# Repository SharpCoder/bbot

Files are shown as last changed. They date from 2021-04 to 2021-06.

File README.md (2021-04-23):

# bbot

bbot - or balancing robot - is a two-wheeled, 3D printed robot which is capable of balancing just like a seguway. The general concept behind the algorithm is: if you are falling forward, move forward. If you are falling backward, move backward. The real challenge comes in doing this quickly and accurately enough.

picture of the robot with most parts assembled

## Components

The main components for bbot are as follows:

 - Adafruit Metro Mini (Arduino)
 - ADXL335 (Accelerometer)
 - SparkFun OpenLog (Telemetry to SDCard)
 - 595N (Shift Register)
 - 2x L293D (H-Bridge)
 - 2x Stepper Motors

## Project Files

The project is split out into different folders. Each folder is responsible for a different aspect of the robot design.

 - **bbot-firmware**: _The arduino source code_
 - **bbot-jupyter**: _A jupyter notebook used to analyze sensor readings_
 - **bbot-models**: _SolidWorks models, as well as finalized STL files_
 - **bbot-pcb**: _KiCAD circuit board and gerber files_

## bbot-firmware

### Overview

The algorithm which is currently implemented takes the approach of measuring the accelerometer sensor readings every 30ms and then comparing the observed values with a known threshold. If the readings indicate it is tilting forward, the robot will activate the step-forward routine for each motor. If the readings indicate it is tilting backward, the robot will activate the step-backward routine for each motor.

In order to actually move the motors, two primary files are responsible. The first being `motors.h` and `motors.cpp`. This code is designed to track which phase of each motor is active at any point in time. Knowing what phase is active allows us to determine what move to take in order to transition to a forward or backward step state. The H-Bridge is actually wired up to a shift register and to activate it, we must keep track of which pins are active in the shift register. The code which handles this is in the files `shift.h` and `shift.cpp`. Managing the shift register is relatively straightforward and simply requires sending an int array containing the state of each pin.

Collecting telemetry is an important part of this project, so that the thresholds can be tweaked in order to improve the algorithm. The `logger.h` and `logger.cpp` files are responsible for this. By leveraging a Sparkfun OpenLog, we are able to stream telemetry data to an SDCard. Each time the sensor is observed, its readings are written to the SDCard.

### Building

You can build the code through the arduino IDE. The microcontroller I used is the Adafruit Metro Mini, which is compatible with most Arduino board targets (for example: Arduino Pro Mini).

## Jupyter Notebook

## 3D Models
TBD

## Assembly Instructions
TBD

## License

All source code and models are provided under the MIT license.

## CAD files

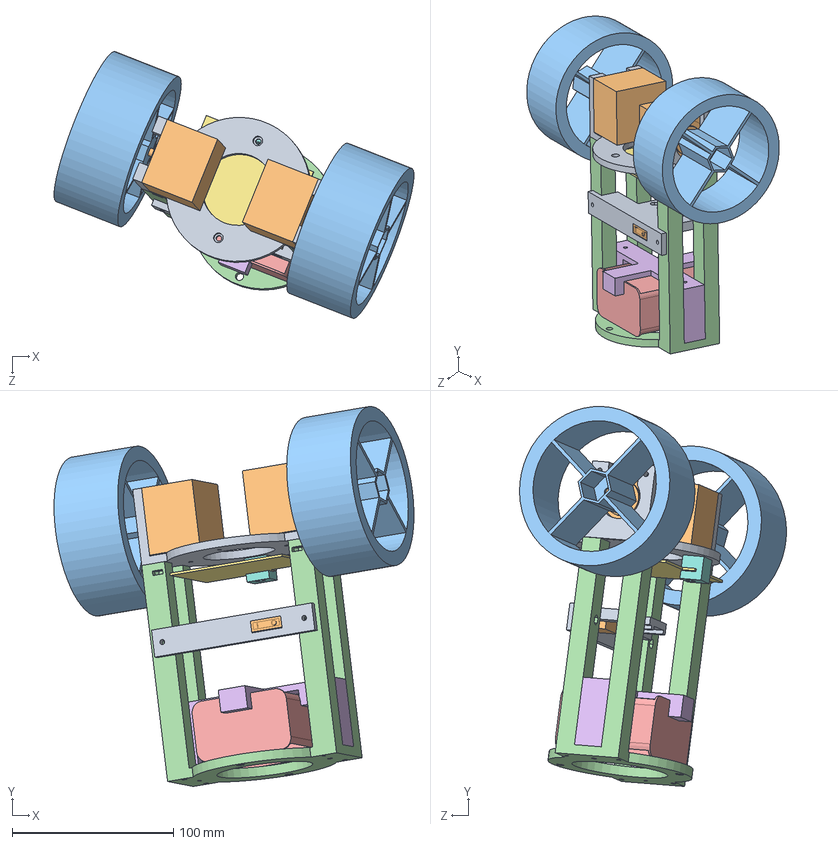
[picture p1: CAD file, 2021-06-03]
bbot-models/full-assembly.SLDASM
223.2 x 235.6 x 165.5 mm
motor-mount
nema17 x 2
wheel x 2
deck
battery-pack
battery-mount
circuit-board
circuit-board-mount
mid-deck
switch

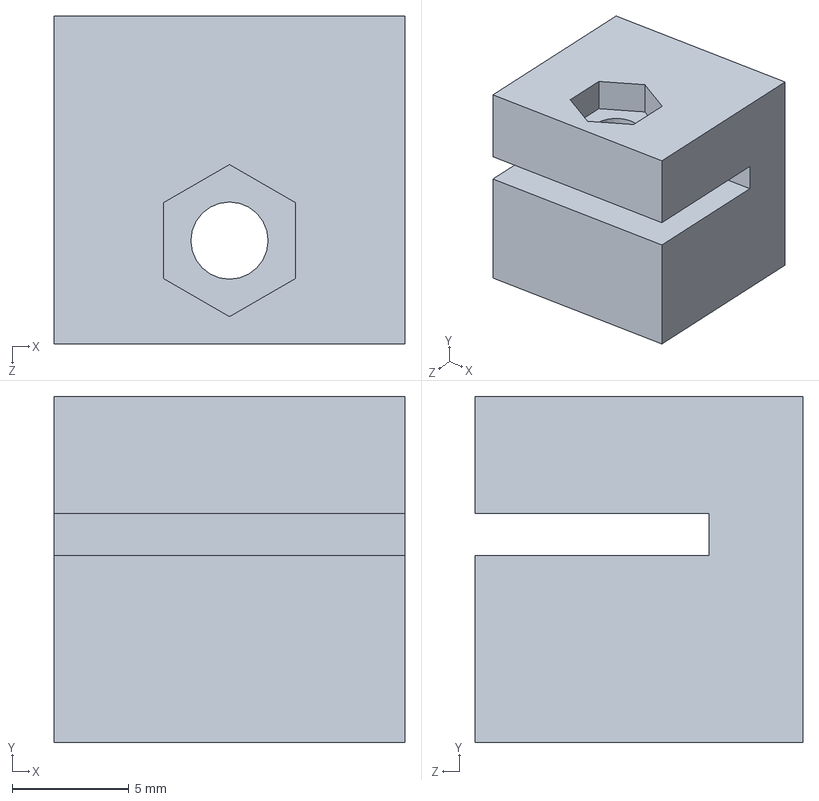
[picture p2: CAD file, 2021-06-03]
bbot-models/chassis/circuit-board-mount.SLDPRT
15.0 x 14.8 x 14.0 mm

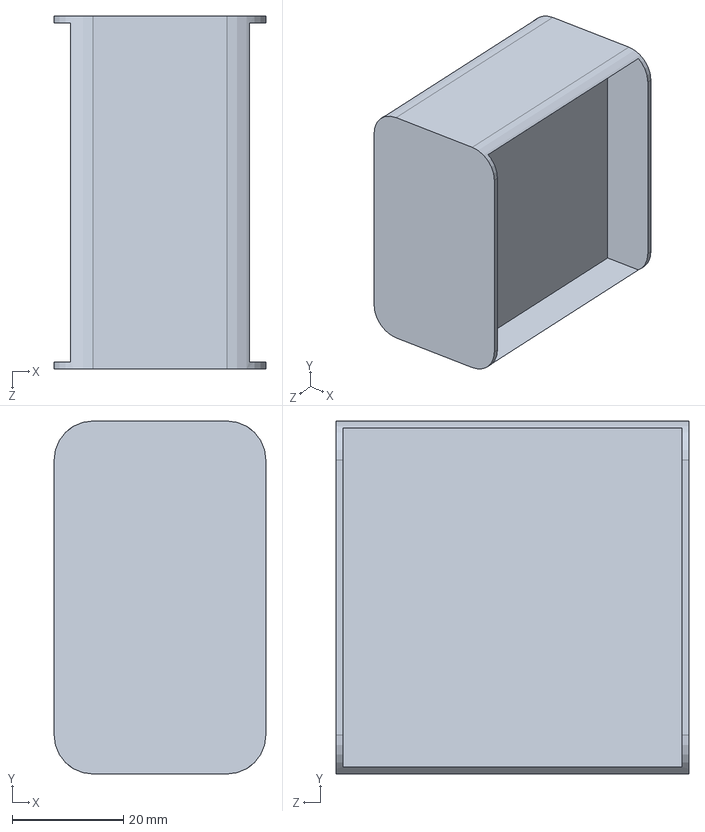
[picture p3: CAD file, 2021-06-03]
bbot-models/cosmetic/battery-pack.SLDPRT
38.1 x 63.5 x 63.5 mm

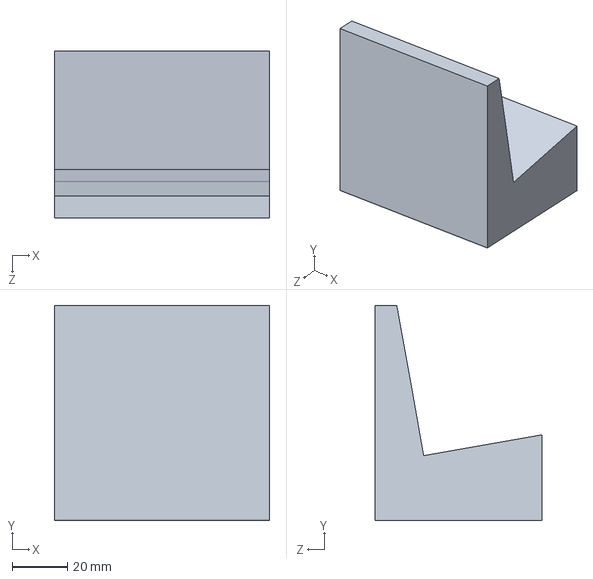
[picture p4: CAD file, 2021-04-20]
bbot-models/debug/block-10d-angle.SLDPRT
78.0 x 78.0 x 60.8 mm

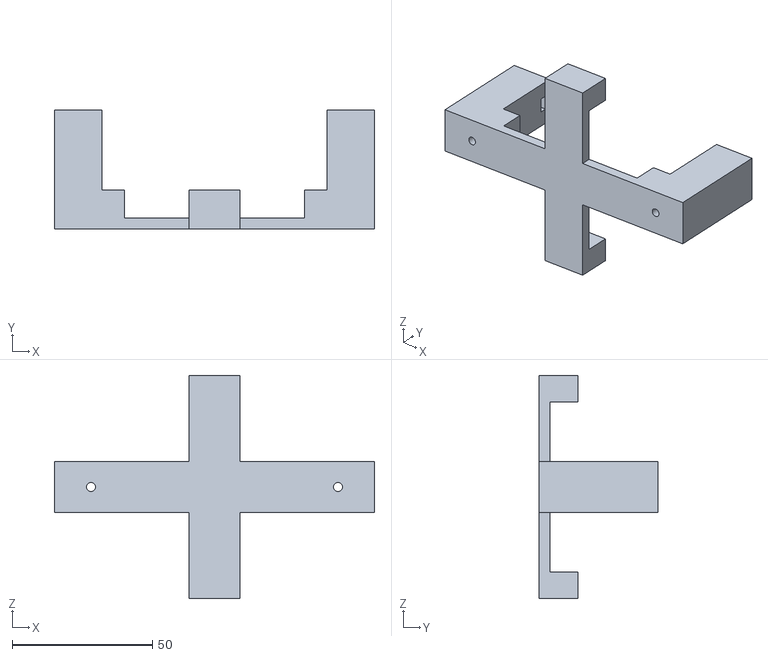
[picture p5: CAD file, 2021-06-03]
bbot-models/STL_FILES/battery-mount.STL
114.0 x 42.5 x 79.5

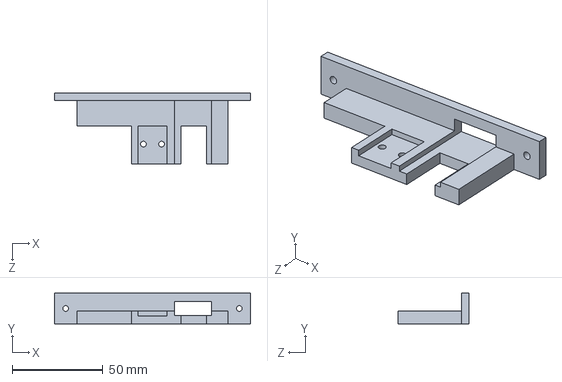
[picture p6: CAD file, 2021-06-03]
bbot-models/chassis/mid-deck.SLDPRT
108.0 x 17.0 x 39.2 mm

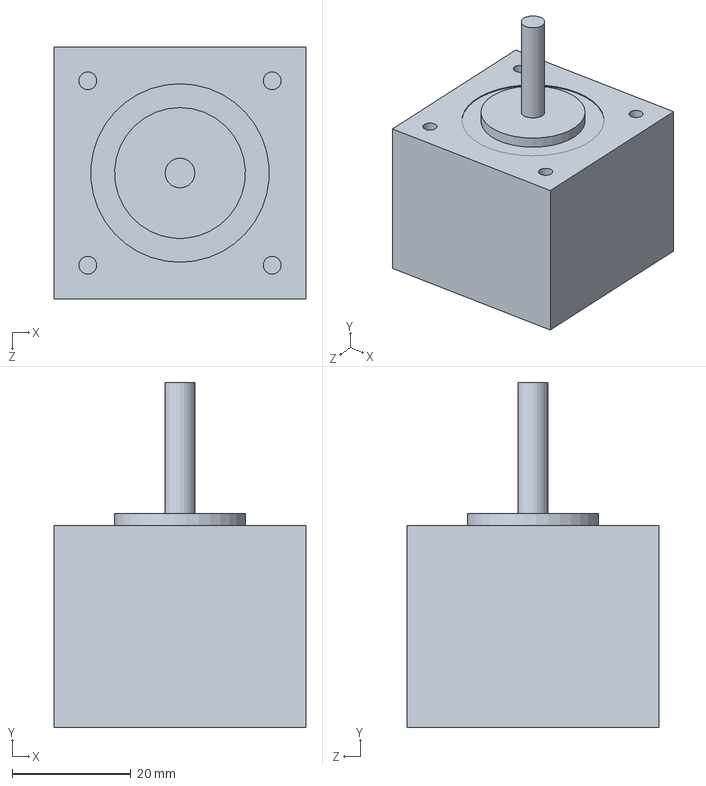
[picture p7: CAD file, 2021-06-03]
bbot-models/cosmetic/nema17.SLDPRT
42.3 x 58.0 x 42.3 mm

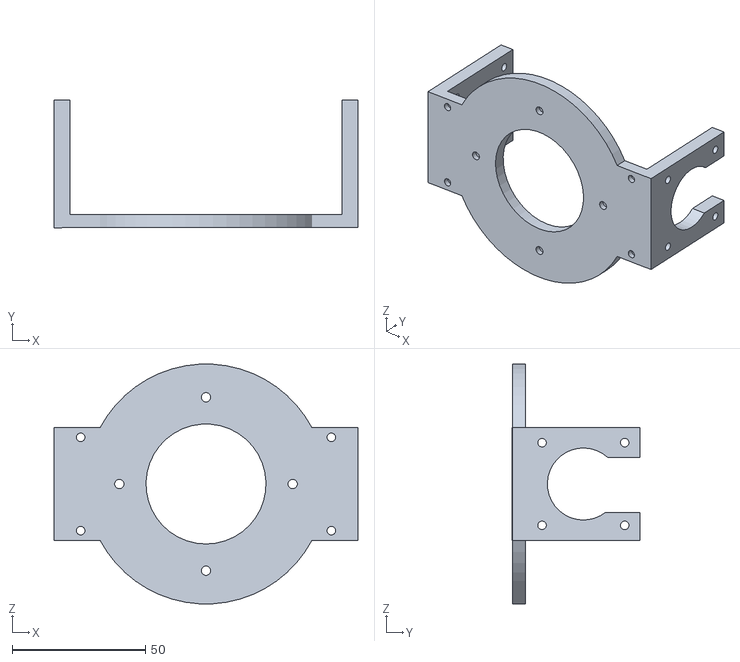
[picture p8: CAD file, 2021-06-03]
bbot-models/STL_FILES/motor-mount.STL
114.0 x 47.8 x 89.9

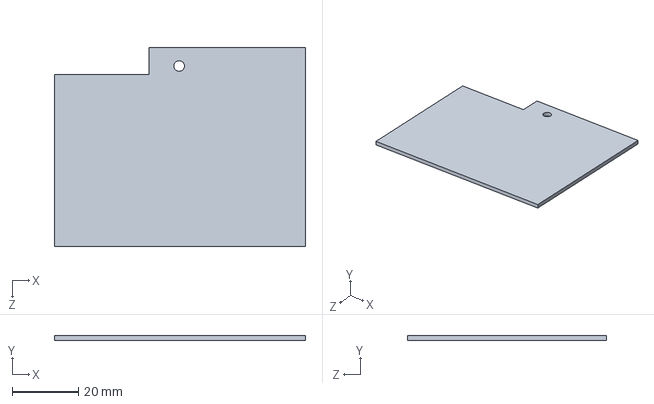
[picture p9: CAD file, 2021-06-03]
bbot-models/cosmetic/circuit-board.SLDPRT
75.7 x 1.50 x 60.0 mm

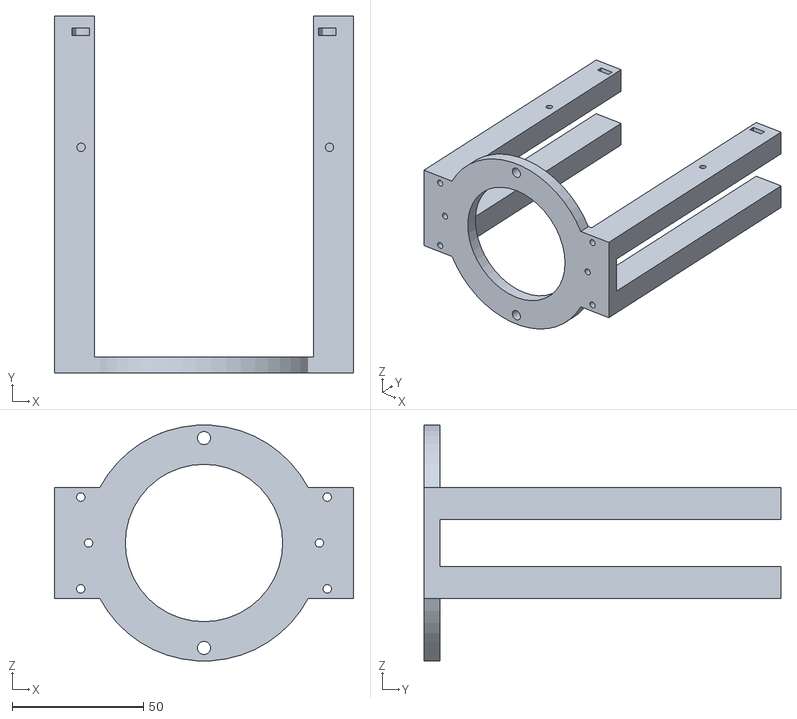
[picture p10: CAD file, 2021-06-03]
bbot-models/STL_FILES/deck.STL
114.0 x 136.0 x 89.8

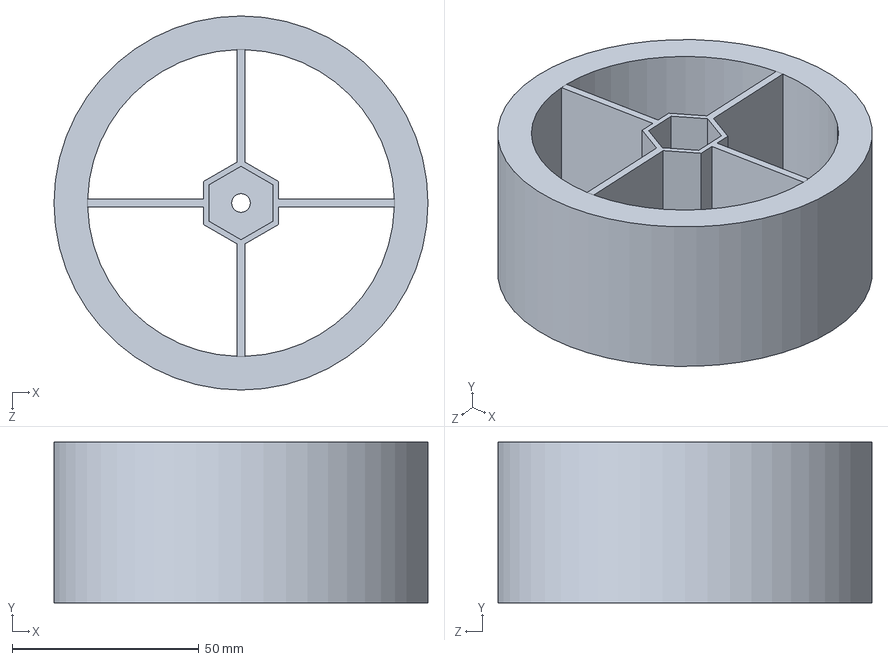
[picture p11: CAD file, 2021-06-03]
bbot-models/cosmetic/wheel.SLDPRT
100.0 x 43.0 x 100.0 mm

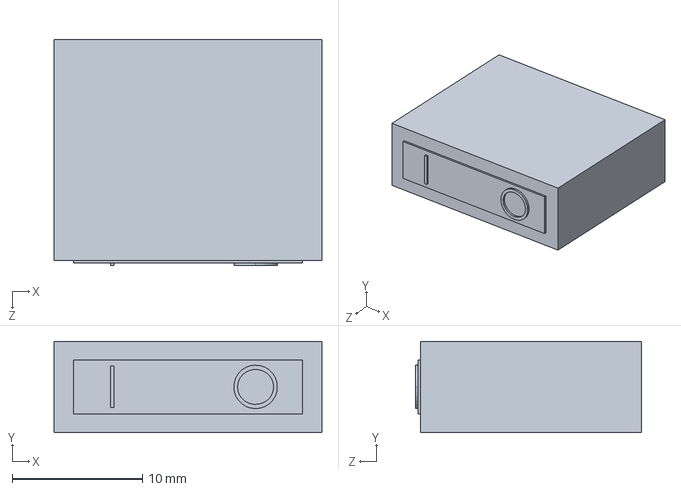
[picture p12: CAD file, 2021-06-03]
bbot-models/cosmetic/switch.SLDPRT
20.6 x 7.00 x 17.4 mm

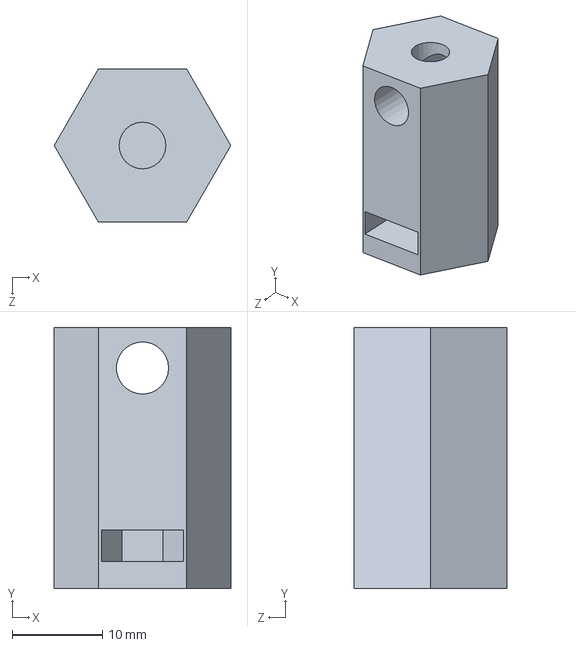
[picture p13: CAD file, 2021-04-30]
bbot-models/chassis/wheel-mount.SLDPRT
19.6 x 29.0 x 17.0 mm

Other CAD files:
bbot-models/chassis/motor-mount.SLDPRT
bbot-models/chassis/battery-mount.SLDPRT
bbot-models/STL_FILES/circuit-board-mount.STL
bbot-models/chassis/deck.SLDPRT
bbot-models/STL_FILES/mid-deck.STL
bbot-models/STL_FILES/block-10d-angle.STL
bbot-models/STL_FILES/washer.STL
bbot-models/STL_FILES/wheel-mount.STL
bbot-models/chassis/washer.SLDPRT
bbot-models/cosmetic/component-box.SLDPRT

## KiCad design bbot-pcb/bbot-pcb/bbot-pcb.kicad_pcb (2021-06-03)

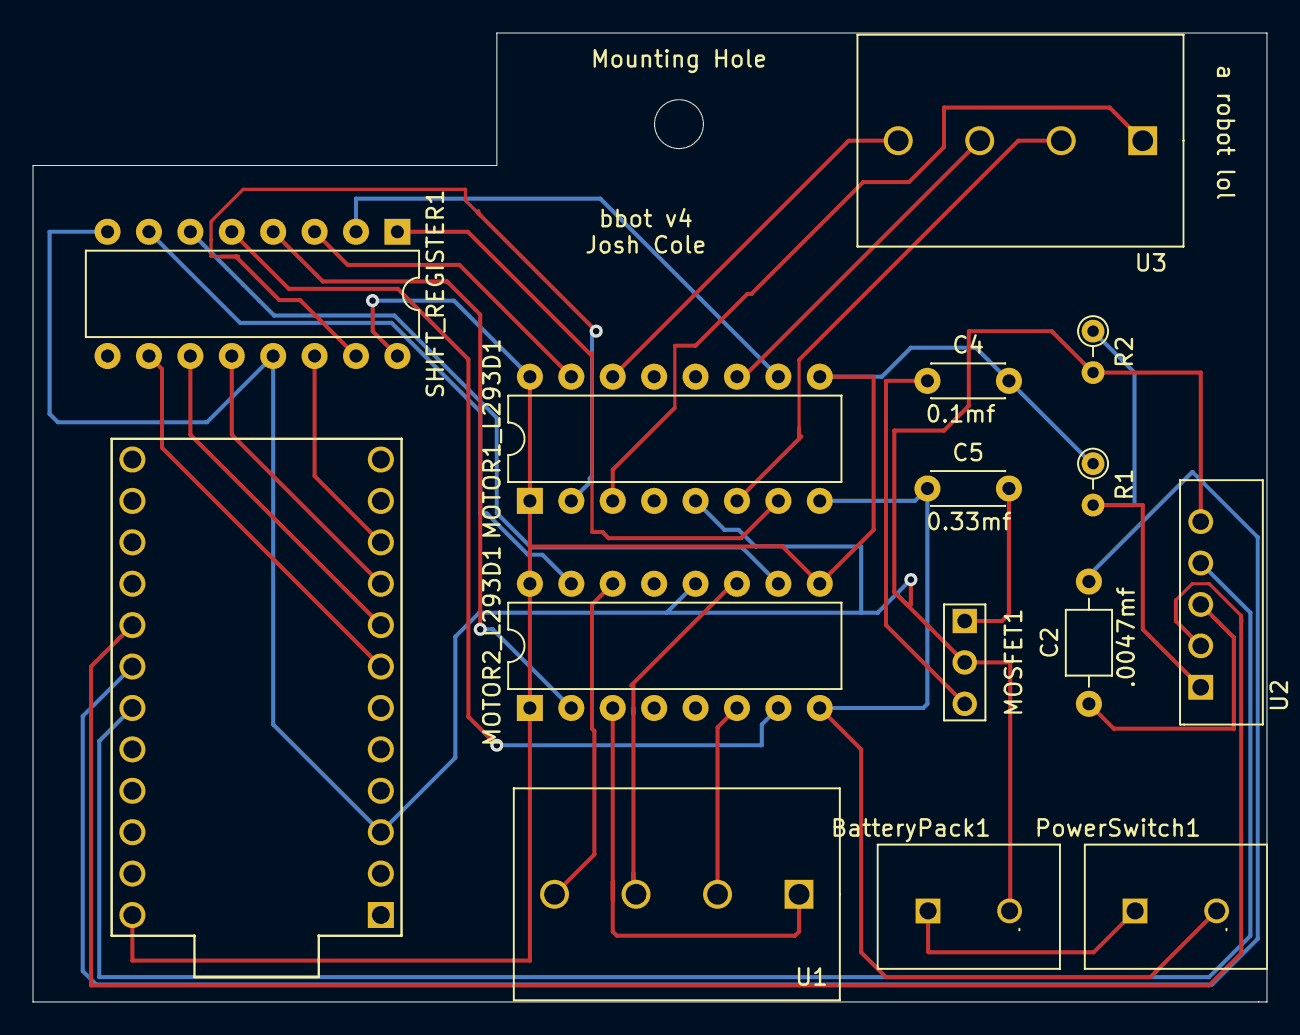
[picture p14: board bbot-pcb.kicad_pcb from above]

Board: 2 copper layers, 75.7 x 59.4 mm, 16 parts (0 on the bottom side), 31 nets.

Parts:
BatteryPack1: Screw_Terminal_2
C2: C.0047mf; C_Axial_L3.8mm_D2.6mm_P7.50mm_Horizontal
C4: L7805_OUT_CAP; C_Disc_D4.3mm_W1.9mm_P5.00mm
C5: L7805_IN_CAP; C_Disc_D4.3mm_W1.9mm_P5.00mm
MOSFET1: L7805; L7805-A
MOTOR1_L293D1, MOTOR2_L293D1: L293D; DIP-16_W7.62mm
Mounting Hole: MountingHole_3mm
PowerSwitch1: Screw_Terminal_2
R1, R2: SPARKFUN-RESISTORS_4.7KOHM-0603-1_10W-1%; R_Axial_DIN0204_L3.6mm_D1.6mm_P2.54mm_Vertical
SHIFT_REGISTER1: 74HC595; DIP-16_W7.62mm
U1, U3: HA-552-4P; HA-522P-Latch_Terminal
U2: ADXL335
U4: ArduinoProMicro; ProMicro

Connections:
/3V: R1.2, R2.1, U2.1
/5V: C4.2, MOTOR1_L293D1.1, MOTOR1_L293D1.9, MOTOR1_L293D1.16, MOTOR2_L293D1.1, MOTOR2_L293D1.9, MOTOR2_L293D1.16, R1.1, SHIFT_REGISTER1.16, U4.24
/12V: C5.1, MOTOR1_L293D1.8, MOTOR2_L293D1.8, PowerSwitch1.2
/A0: U2.2, U4.17
/A1: C2.2, U4.18
/A2: U2.4, U4.19
/GND: BatteryPack1.2, MOSFET1.2, MOTOR1_L293D1.5, MOTOR2_L293D1.12, R2.2, SHIFT_REGISTER1.8, SHIFT_REGISTER1.13, U2.5, U4.3
/MOTOR1_A: MOTOR1_L293D1.2, SHIFT_REGISTER1.15
/MOTOR1_B: MOTOR1_L293D1.7, SHIFT_REGISTER1.1
/MOTOR1_C: MOTOR1_L293D1.10, SHIFT_REGISTER1.2
/MOTOR1_D: MOTOR1_L293D1.15, SHIFT_REGISTER1.3
/MOTOR1_PHASE_A: MOTOR1_L293D1.3, U3.1
/MOTOR1_PHASE_B: MOTOR1_L293D1.6, U3.2
/MOTOR1_PHASE_C: MOTOR1_L293D1.11, U3.3
/MOTOR1_PHASE_D: MOTOR1_L293D1.14, U3.4
/MOTOR2_A: MOTOR2_L293D1.2, SHIFT_REGISTER1.4
/MOTOR2_B: MOTOR2_L293D1.7, SHIFT_REGISTER1.5
/MOTOR2_C: MOTOR2_L293D1.10, SHIFT_REGISTER1.6
/MOTOR2_D: MOTOR2_L293D1.15, SHIFT_REGISTER1.7
/MOTOR2_PHASE_A: MOTOR2_L293D1.3, U1.1
/MOTOR2_PHASE_B: MOTOR2_L293D1.6, U1.2
/MOTOR2_PHASE_C: MOTOR2_L293D1.11, U1.3
/MOTOR2_PHASE_D: MOTOR2_L293D1.14, U1.4
/SHIFT_CLCK: SHIFT_REGISTER1.11, U4.8
/SHIFT_CLR: SHIFT_REGISTER1.10, U4.7
/SHIFT_DATA: SHIFT_REGISTER1.14, U4.10
/SHIFT_LATCH: SHIFT_REGISTER1.12, U4.9
unnamed: BatteryPack1.1, PowerSwitch1.1
unnamed: C2.1, U2.3
unnamed: C4.1, MOSFET1.3
unnamed: C5.2, MOSFET1.1

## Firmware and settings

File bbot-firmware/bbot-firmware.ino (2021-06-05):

/*
   bbot-firmware.ino
   ------------------------------
   This is the entrypoint to bbot. A 2-wheel balancing robot
   which uses an accelerometer to stabilize itself. All pins can be
   configured using the pinout.h header file.

   bbot-firmware uses the following components:
   74HC595N Shift Register
   2x bi-phasic 4-wire stepper motor
   HMC5883L accelerometer
*/
#include <Arduino.h>
#include "adxl335.h"
#include "motors.h"
#include "pinout.h"
#include "shift.h"
#include "timer.h"

#define MOTOR_LOOP_DELAY 9
#define GRAVITY_NEUTRAL 308.0
#define GRAVITY_THRESHOLD 3.0
#define GRAVITY_CRASHED 65.0
#define GRAVITY_AVG_COUNT 9.0

enum AIGravityState { 
  FALLING_FORWARD,
  FALLING_BACKWARD,
  STABLE,
  CRASHED,
};

VectorData compass_data;
AIGravityState real_gravity_state = STABLE;
AIGravityState active_gravity_state = STABLE;

float avg_rotation_base = 0.0;
float avg_rotation_count = 0.0;
long motor_loop_target_ms = 0;

boolean crashed = false;
void setup() {
  // Indicator light representing total system shutdown
//  pinMode(LED_BUILTIN, OUTPUT);
//  digitalWrite(LED_BUILTIN, LOW);

  // Accelerometer
  pinMode(COMPASS_X_PIN, INPUT);
  pinMode(COMPASS_Y_PIN, INPUT);
  pinMode(COMPASS_Z_PIN, INPUT);

  // Shift register pins
  pinMode(SHIFT_REG_CLCK, OUTPUT);
  pinMode(SHIFT_REG_DATA, OUTPUT);
  pinMode(SHIFT_REG_LATCH, OUTPUT);
  pinMode(SHIFT_REG_CLEAR, OUTPUT);

  // Serial used for debugging
  Serial.begin(115200);

  // Spend 2 seconds calculating the average accelerometer reading.
  // This does two things.
  // First - It is a built-in wait timer for the application start.
  // Second - It allows us to calculate a rolling average from here on out.
  for (int i = GRAVITY_AVG_COUNT; i > 0; i--) {
    // Update the compass readings
    update_compass();
    delay(2000 / GRAVITY_AVG_COUNT);
  }

//  // Initalize peripherals and subsystems
  timer_init();
}

void loop() {
  // Robot will remain idle after a crash
  if (crashed) {
    return;
  }
  
  defer(ai_main, 28);
  defer(update_compass, 4);

  // This will handle orchestrating all currently
  // open threads which need processing.
  process_timers();
  process_motor_loop();
}

/*
    Function: update_compass
    ---------------------------------------------------
    This method simply calls the compass_read function
    and saves the current data in a global variable.
*/
void update_compass(void) {
  compass_data = compass_read();

  // While we're at it, update the
  // rolling average rotation value.
  float rotation = get_rotation(compass_data);
  if (avg_rotation_count < GRAVITY_AVG_COUNT) {
    avg_rotation_base += rotation;
    avg_rotation_count++;
  } else {
    avg_rotation_base = avg_rotation_base - (avg_rotation_base / GRAVITY_AVG_COUNT) + rotation;
  }
}

/*
    Function: get_rotation
    ---------------------------------------------------
    A convenience method which returns the axis
    representing rotation based on the sensor
    orientation. Since it's mounted in a specific
    and non-standard axis.
*/
float get_rotation(VectorData data) {
  return data.y;
}

/*
    Function: ai_compute_gravity_state
    ---------------------------------------------------
    This method will take some vector data and return
    the current state of the robot relative to gravity.
    I.E. are we falling, if so, which direction.
*/
AIGravityState ai_compute_gravity_state(VectorData data) {
  float rotation = get_rotation(data);
  float avg_rotation = avg_rotation_base / avg_rotation_count;
  float dist_to_neutral = abs(GRAVITY_NEUTRAL - rotation);
  float avg_dist_to_neutral = abs(GRAVITY_NEUTRAL - avg_rotation);
  
//  Serial.print("<");
//  Serial.print("[");
//  Serial.print(millis());
//  Serial.print(",");
//  Serial.print(avg_rotation);
//  Serial.print(",");
//  Serial.print(rotation);
//  Serial.print(",");
//  Serial.print(data.x);
//  Serial.print(",");
//  Serial.print(data.y);
//  Serial.print(",");
//  Serial.print(data.z);
//  Serial.println("],");
//  
//  Serial.print("dist_to_neutral: ");
//  Serial.println(avg_dist_to_neutral);
  
  if (avg_dist_to_neutral > GRAVITY_CRASHED) {
    // We are in a very bad state
    return CRASHED;
  } else if (avg_dist_to_neutral > GRAVITY_THRESHOLD) {
    // We are falling
    if (avg_rotation > GRAVITY_NEUTRAL) {
      return FALLING_FORWARD;
    } else {
      return FALLING_BACKWARD;
    }
  } else {
    // We are in a neutral state
    return STABLE;
  }
}

/*
    Function: ai_main
    ---------------------------------------------------
    This method is the primary logic for the algorithm.

    General theory: move in the direction we are
    falling. To achieve this, we must be constantly
    polling the accelerometer to determine direction
    we are falling. With these readings, we will decide
    which direction each respective motor needs to be
    moving.
*/
void ai_main() {
  real_gravity_state = ai_compute_gravity_state(compass_data);
}

void process_motor_loop() {
  long now = millis();
  if (real_gravity_state != active_gravity_state || now > motor_loop_target_ms) {
    switch (active_gravity_state) {
      case FALLING_FORWARD: {
        step_forward(MotorLeft);
        step_forward(MotorRight);
      }
      break;
      case FALLING_BACKWARD: {
        step_backward(MotorLeft);
        step_backward(MotorRight);
      }
      break;
      case STABLE: {
        // Do nothing
      }
      break;
      case CRASHED: {
        if (crashed != true) {
          Serial.println("CRASHED");
        }
        crashed = true;
      }
      break;
    }

    motor_loop_target_ms = millis() + MOTOR_LOOP_DELAY;
    active_gravity_state = real_gravity_state;
  }
}

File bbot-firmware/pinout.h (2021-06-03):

#ifndef __PINOUT_H_
#define __PINOUT_H_

#include <Arduino.h>

/*
 * INDICATORS
 */
 #define  CRASHMODE_LED_PIN 13

/*
 * ADXL335 ACCELEROMETER
 */
 #define  COMPASS_X_PIN A0
 #define  COMPASS_Y_PIN A1
 #define  COMPASS_Z_PIN A2

/* 
 *  SHIFT REGISTER
 *  These values represent the shift register pins
 *  which are directly connected to the arduino.
 */
#define SHIFT_REG_CLEAR 4
#define SHIFT_REG_CLCK  5
#define SHIFT_REG_LATCH 6
#define SHIFT_REG_DATA  7

/* 
  MOTORS
  Each motor is hooked up to the shift register. The value
  represents which pin index that particular phase (A-D) is
  configured against.
*/

#define MOTOR_1_A  0
#define MOTOR_1_B  1
#define MOTOR_1_C  2
#define MOTOR_1_D  3
#define MOTOR_2_A  4
#define MOTOR_2_B  5
#define MOTOR_2_C  6
#define MOTOR_2_D  7


#endif

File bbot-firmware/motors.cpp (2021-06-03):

#include "motors.h"


// Which phase each motor is currently in
int motor_phases[] = {0,0};

/* Assuming index 0 - 3 is motor 1, 4 - 7 is motor 2. This map represents
 * a particular motor-phase and corresponds it to a pin on the shift register.
 * By using this map lookup, we can change which phase maps to which pin through a
 * global definition instead of making assumptions.
 */
int phase_pin_map[] = { MOTOR_1_A, MOTOR_1_C, MOTOR_1_B, MOTOR_1_D, MOTOR_2_A, MOTOR_2_C, MOTOR_2_B, MOTOR_2_D };

// This represents which shift register pins are currently HIGH.
int shift_register_values[8] =  {0,0,0,0,0,0,0,0};

/* 
 *  Function: _compute_offest
 *  ---------------------------------------------------
 *  This method computes the offset of a particular
 *  motor. The first motor has no offset, the second
 *  motor has an offset of 4. This is because
 *  the shift register has 8 channels and each motor
 *  uses a different set of them.
 */
int _compute_offest(motor_t motor) {
  if (motor == MotorRight) {
    return 4;
  } else {
    return 0;
  }
}

/* 
 *  Function: _set_phase
 *  ---------------------------------------------------
 *  This method will take a motor and a phase
 *  and update the shift register data object
 *  while applying the result into the shift register.
 */
void _set_phase(motor_t motor, int phase) {
  int offset = _compute_offest(motor);
  for (int phase_idx = 0; phase_idx < 4; phase_idx++) {
    // For a given index, lookup the pin mapping
    int phase_pin = phase_pin_map[offset + phase_idx];
    // Then we can zero out the particular pin in question
    shift_register_values[phase_pin] = 0;
  }

  // For the selected phase, lookup the pin mapping
  int phase_pin = phase_pin_map[offset + phase];
  shift_register_values[phase_pin] = 1;

  // Use the shift.h function to apply values.
  update_shift_registers(shift_register_values);  
}

/* 
 *  Function: _step
 *  ---------------------------------------------------
 *  This method will take a motor and a direction
 *  and update the stepper phase in order to achieve
 *  movement in the particular direction.
 */
void _step(motor_t motor, bool forward) {
  int index = _compute_offest(motor) / 4;

  // Compute the next phase
  if (forward) {
    motor_phases[index] = motor_phases[index] + 1;
  } else {
    motor_phases[index] = motor_phases[index] - 1;
  }

  // Handle boundary overflow
  if (motor_phases[index] > MAX_PHASE) {
    motor_phases[index] = MIN_PHASE;
  } else if (motor_phases[index] < MIN_PHASE) {
    motor_phases[index] = MAX_PHASE;
  }

  // Apply
  _set_phase(motor, motor_phases[index]);
}

/* 
 *  Function: stepForward
 *  ---------------------------------------------------
 *  This method will move a particular motor forwards.
 */
void step_forward(motor_t motor) {
  _step(motor, true);  
}

/* 
 *  Function: stepBackward
 *  ---------------------------------------------------
 *  This method will move a particular motor backwards.
 */
void step_backward(motor_t motor) {
  _step(motor, false);
}

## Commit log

2021-04-04 initial commit of project code with some helper functions for motor movement
2021-04-05 fix bugs with the shift register so it is fully addressable
    [bbot-firmware.ino, pinout.h, shift.cpp]
2021-04-05 initial commit of primary chassis and accompanying cosmetic models
    [full-assembly.SLDASM, motor-mount.SLDPRT, nema17.SLDPRT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]
2021-04-05 initial half-baked version of upper deck
    [deck.SLDPRT, full-assembly.SLDASM, motor-mount.SLDPRT]
2021-04-06 Add cosmetic battery pack and accompanying battery mount component
    [battery-mount.SLDPRT, battery-pack.SLDPRT, deck.SLDPRT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]
2021-04-06 Update battery mount and final assembly. begin cosmetic components for electronics
    [battery-mount.SLDPRT, component-box.SLDPRT, deck.SLDPRT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]
2021-04-06 initial kicad design files
    [bbot-pcb.kicad_pcb, bbot-pcb.sch]
2021-04-06 mostly completed library of components for the schematic
2021-04-07 unverified prototype of completed circuit board design. not quite ready to ship off to a fab yet
    [bbot-pcb-B_Cu.gbr, bbot-pcb-B_Mask.gbr, bbot-pcb-B_Paste.gbr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]
2021-04-08 Add i2c docstrings
2021-04-08 finalize kicad circuit board.
    [bbot-pcb-B_Cu.gbr, bbot-pcb-B_Mask.gbr, bbot-pcb-B_Paste.gbr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]
2021-04-09 some tweaks to the models and output the STL files
    [battery-mount.SLDPRT, battery-mount.STL, bbot-pcb.kicad_pcb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]
2021-04-09 create a wheel mounting part which is compatible with my wheels and supports affixing to the wheel and attaching to the motor via a set screw
    [full-assembly.SLDASM, washer.SLDPRT, washer.STL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]
2021-04-09 update to assembly models
    [battery-mount.SLDPRT, battery-pack.SLDPRT, deck.SLDPRT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]
2021-04-12 Add some jupyter notebook for calibrating the accelerometer
2021-04-12 Improve the battery mount and adjacent hardware
    [battery-mount.SLDPRT, battery-mount.STL, full-assembly.SLDASM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]
2021-04-12 OKAY! Improve the compass and timer subsystem.
    This commit is fairly huge. It introduces the concept
    of calibrated values to the compass, as well as code
    to support the self-test functionality of the peripheral.
    By leveraging the learnings of the jupyter notebook,
    some baseline multipliers were derived which help constrain
    and interpret the compass rotation value.
2021-04-19 pcb v2 updates
    [bbot-pcb-B_Cu.gbr, bbot-pcb-B_Mask.gbr, bbot-pcb-B_Paste.gbr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]
2021-04-20 Configure accelerometer pins so they are inputs
2021-04-20 Remove unused libraries, repurpose LED13 as a crash indicator
    [bbot-firmware.ino, pinout.h]
2021-04-20 update readme. update STL files
    [block-10d-angle.SLDPRT, block-10d-angle.STL, full-assembly.SLDASM]
2021-04-21 Add wall guards to captive nut for deck part
    [circuit-board.SLDPRT, deck.SLDPRT, full-assembly.SLDASM]
2021-04-21 create and arrange middle deck for power switch and accelerometer mounting
    [battery-mount.SLDPRT, bbot-pcb.kicad_pcb, circuit-board-mount.SLDPRT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]
2021-04-21 update wheel mount to support captive nut walls
    [full-assembly.SLDASM, wheel-mount.SLDPRT]
2021-04-23 regenerate STL files
    [battery-mount.STL, circuit-board-mount.STL, deck.STL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]
2021-04-24 improve size and stability of motor mount part
    [deck.SLDPRT, full-assembly.SLDASM, motor-mount.SLDPRT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]
2021-04-24 minor tweaks to the mid deck model
    [deck.SLDPRT, full-assembly.SLDASM, mid-deck.SLDPRT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]
2021-04-30 Update PCB to v3
    [bbot-pcb-B_Cu.gbr, bbot-pcb-B_Mask.gbr, bbot-pcb-B_Paste.gbr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]
2021-04-30 Update models to support wider PCB board and address a number of minor tweaks
    [battery-mount.SLDPRT, battery-mount.STL, circuit-board-mount.SLDPRT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]
2021-06-03 RElease-candidate of models and pcb
    [battery-mount.SLDPRT, battery-mount.STL, battery-pack.SLDPRT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]
